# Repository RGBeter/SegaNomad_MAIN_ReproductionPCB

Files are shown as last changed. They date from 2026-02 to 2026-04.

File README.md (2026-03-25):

# Sega Nomad MAIN Reproduction PCB
Reproduction of the Sega Nomad's main board, created from scans provided by Villahed94, Sega's documentation, and community knowledge of the FC1004 style Genesis.
Additional features include TMSS bypass jumpers, SMS support and 32X support.

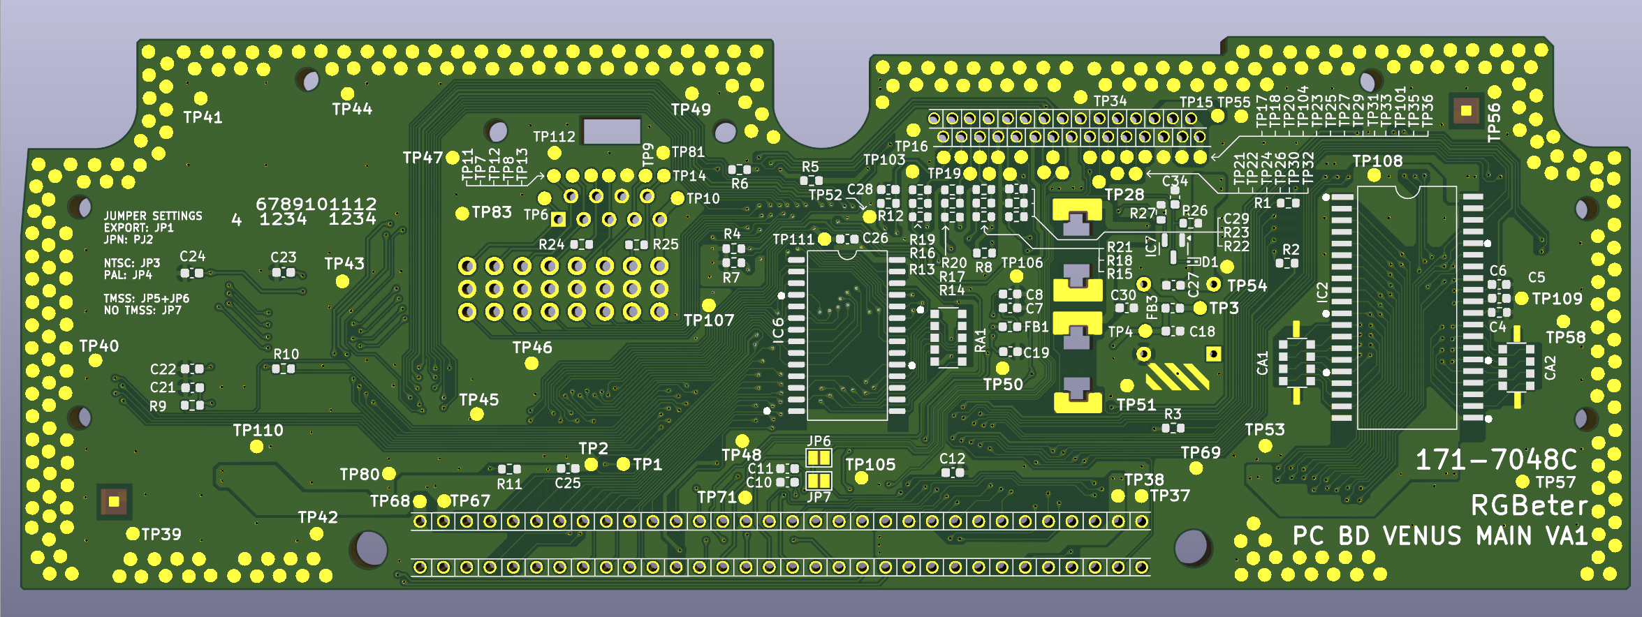
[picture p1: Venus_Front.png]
Front

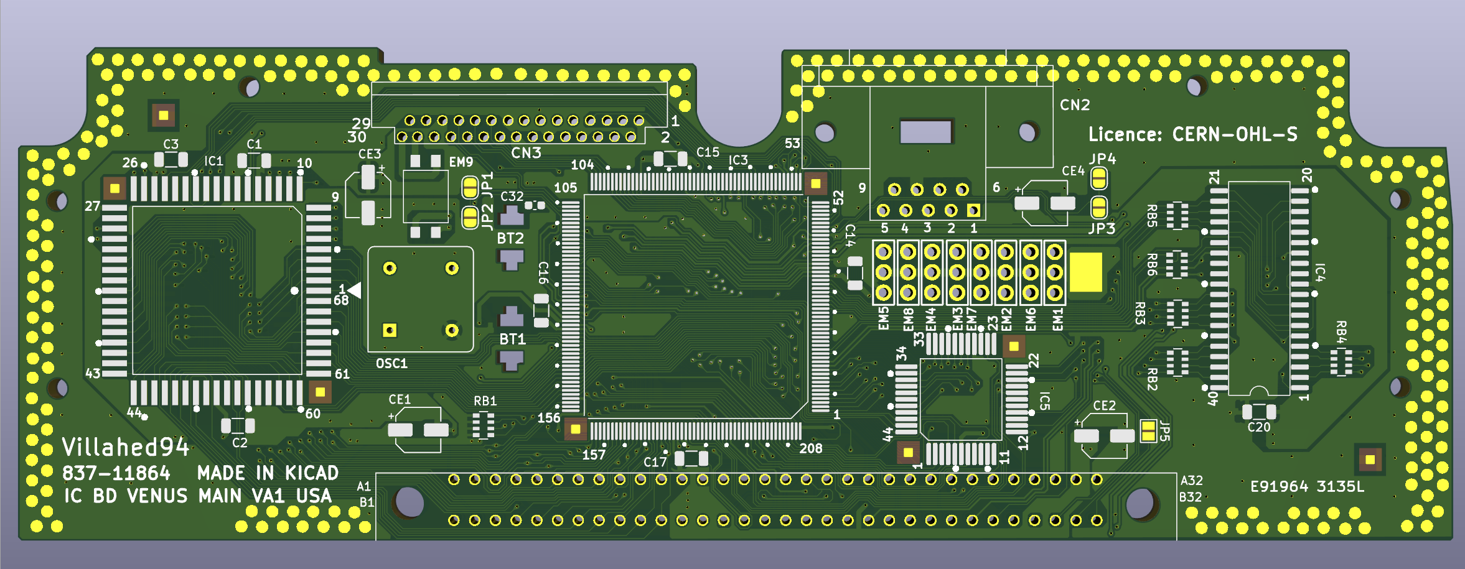
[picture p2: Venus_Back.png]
Back


# Build Notes
These PCBs are tested to work with with a stock VENUS SUB pcb, building these requires skills in microsoldering, QFP soldering, hot air rework, and Mega Drive troubleshooting.
It is highly recomendded you start with a set of known working parts from a donor MegaDrive. VA1, VA1.8 and VA3 Model 2 Sega Genesis/MegaDrive can provide all of the necessary custom chips needed for this build.
Support is not officially provided by neither RGBeter nor Villahed94 with building or debugging these PCBs.

# Production Notes
While Sega utlized a 2 layer PCB for the Nomad, it is best to order these as a 4 layer PCB in order to improve noise across the board
If you wish NOT to include the SRES bypass, add the following bodge wires in order to connect the original 315-5684 based SRES circuit.

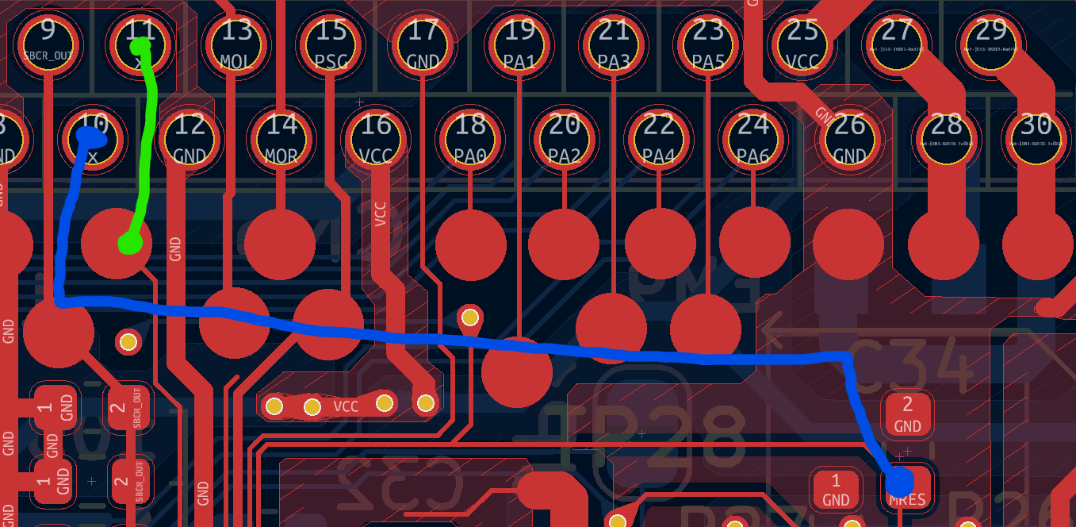
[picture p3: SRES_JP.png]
Bodge Required to use Stock SRES


# BOM
Most of, if not all parts can be directly transplanted from a donor Nomad Main board, however, some alterations have been made, and they are as follows:

R5 + R6, FM DAC limiting resistors best changed to 0 ohms when modding audio

All large MLCC capacitors can have their value increased to 10uF to improve noise

|Component|Value|Note|
|:---|:----|:---|
|IC1|PLCC 68000|CPU|
|IC2|68K RAM|WORK RAM|
|IC3|FC1004/FF1004|MAIN ASIC|
|IC4|VIDEO RAM|VRAM|
|IC5|QFP Z80|Z80 CPU|
|IC6|Z80 RAM|ZRAM|
|IC7|LM809|SRES BYPASS ONLY|
|C1|10uF|1206 X7R|
|C2|10uF|1206 X7R|
|C3|10uF|1206 X7R|
|C4|47pF|0603 C0G 315-5708 ONLY|
|C5|100pF|0603 C0G|
|C6|100pF|0603 C0G|
|C7|22pF|0603 C0G|
|C8|1000pF|0603 C0G|
|C9|N/A|DOES NOT EXIST|
|C10|100pF|0603 C0G|
|C11|100pF|0603 C0G|
|C12|33pF|0603 C0G|
|C13|N/A|DOES NOT EXIST|
|C14|10uF|1206 X7R|
|C15|10uF|1206 X7R|
|C16|10uF|1206 X7R|
|C17|10uF|1206 X7R|
|C18|20pF|0603 C0G|
|C19|47pF|0603 C0G|
|C20|10uF|1206 X7R|
|C21|33pF|0603 C0G DO NOT POPULATE|
|C22|100pF|0603 C0G|
|C23|33pF|0603 C0G|
|C24|100pF|0603 C0G|
|C25|0.1uF|0603 X7R|
|C26|0.1uF|0603 X7R|
|C27|0.1uF|0603 X7R|
|C28|N/A|DO NOT POPULATE|
|C29|100pF|0603 C0G|
|C30|0.1uF|0603 X7R|
|C31|N/A|DOES NOT EXIST|
|C32|N/A|DO NOT POPULATE|
|C33|N/A|DOES NOT EXIST|
|C30|1uF|0603 X7R SRES BYPASSS ONLY|
|CE1|47uF 6v|SMD ELEC, CAN REPLACE WITH TANTALUM|
|CE2|47uF 6v|SMD ELEC, CAN REPLACE WITH TANTALUM|
|CE3|100uF 6v|SMD ELEC, CAN REPLACE WITH TANTALUM|
|CE4|47uF 6v|SMD ELEC, CAN REPLACE WITH TANTALUM|
|D1|SOD-923 DIODE|SRES BYPASS ONLY|
|OSC1|MCLK OSCILATOR, SQUARE PACKAGE|CHECK REGION|
|R1|150R|0603|
|R2|220R|0603|
|R3|2.2K|0603|
|R4|220R|0603|
|R5|0R|0603 DAC LIMITING RESISTOR|
|R6|0R|0603 DAC LIMITING RESISTOR|
|R7|2.2K|0603|
|R8|4.7K|0603|
|R9|100R|0603|
|R10|100R|0603|
|R11|2.2K|0603|
|R12|2.2K|0603|
|R13|5.6K|0603|
|R14|5.6K|0603|
|R15|5.6K|0603|
|R16|4.7K|0603|
|R17|4.7K|0603|
|R18|4.7K|0603|
|R19|1.2K|0603|
|R20|1.2K|0603|
|R21|1.2K|0603|
|R22|4.7K|0603|
|R23|1.0K|0603|
|R24|330R|0603|
|R25|330R|0603|
|R26|2.2K|0603|
|R27|100K|0603|
|RA1|4.7K|5X1206 BANK|
|RB1|2.2K|4X0603 BANK|
|RB2|100R|4X0603 BANK|
|RB3|100R|4X0603 BANK|
|RB4|100R|4X0603 BANK|
|RB5|100R|4X0603 BANK|
|RB6|100R|4X0603 BANK|

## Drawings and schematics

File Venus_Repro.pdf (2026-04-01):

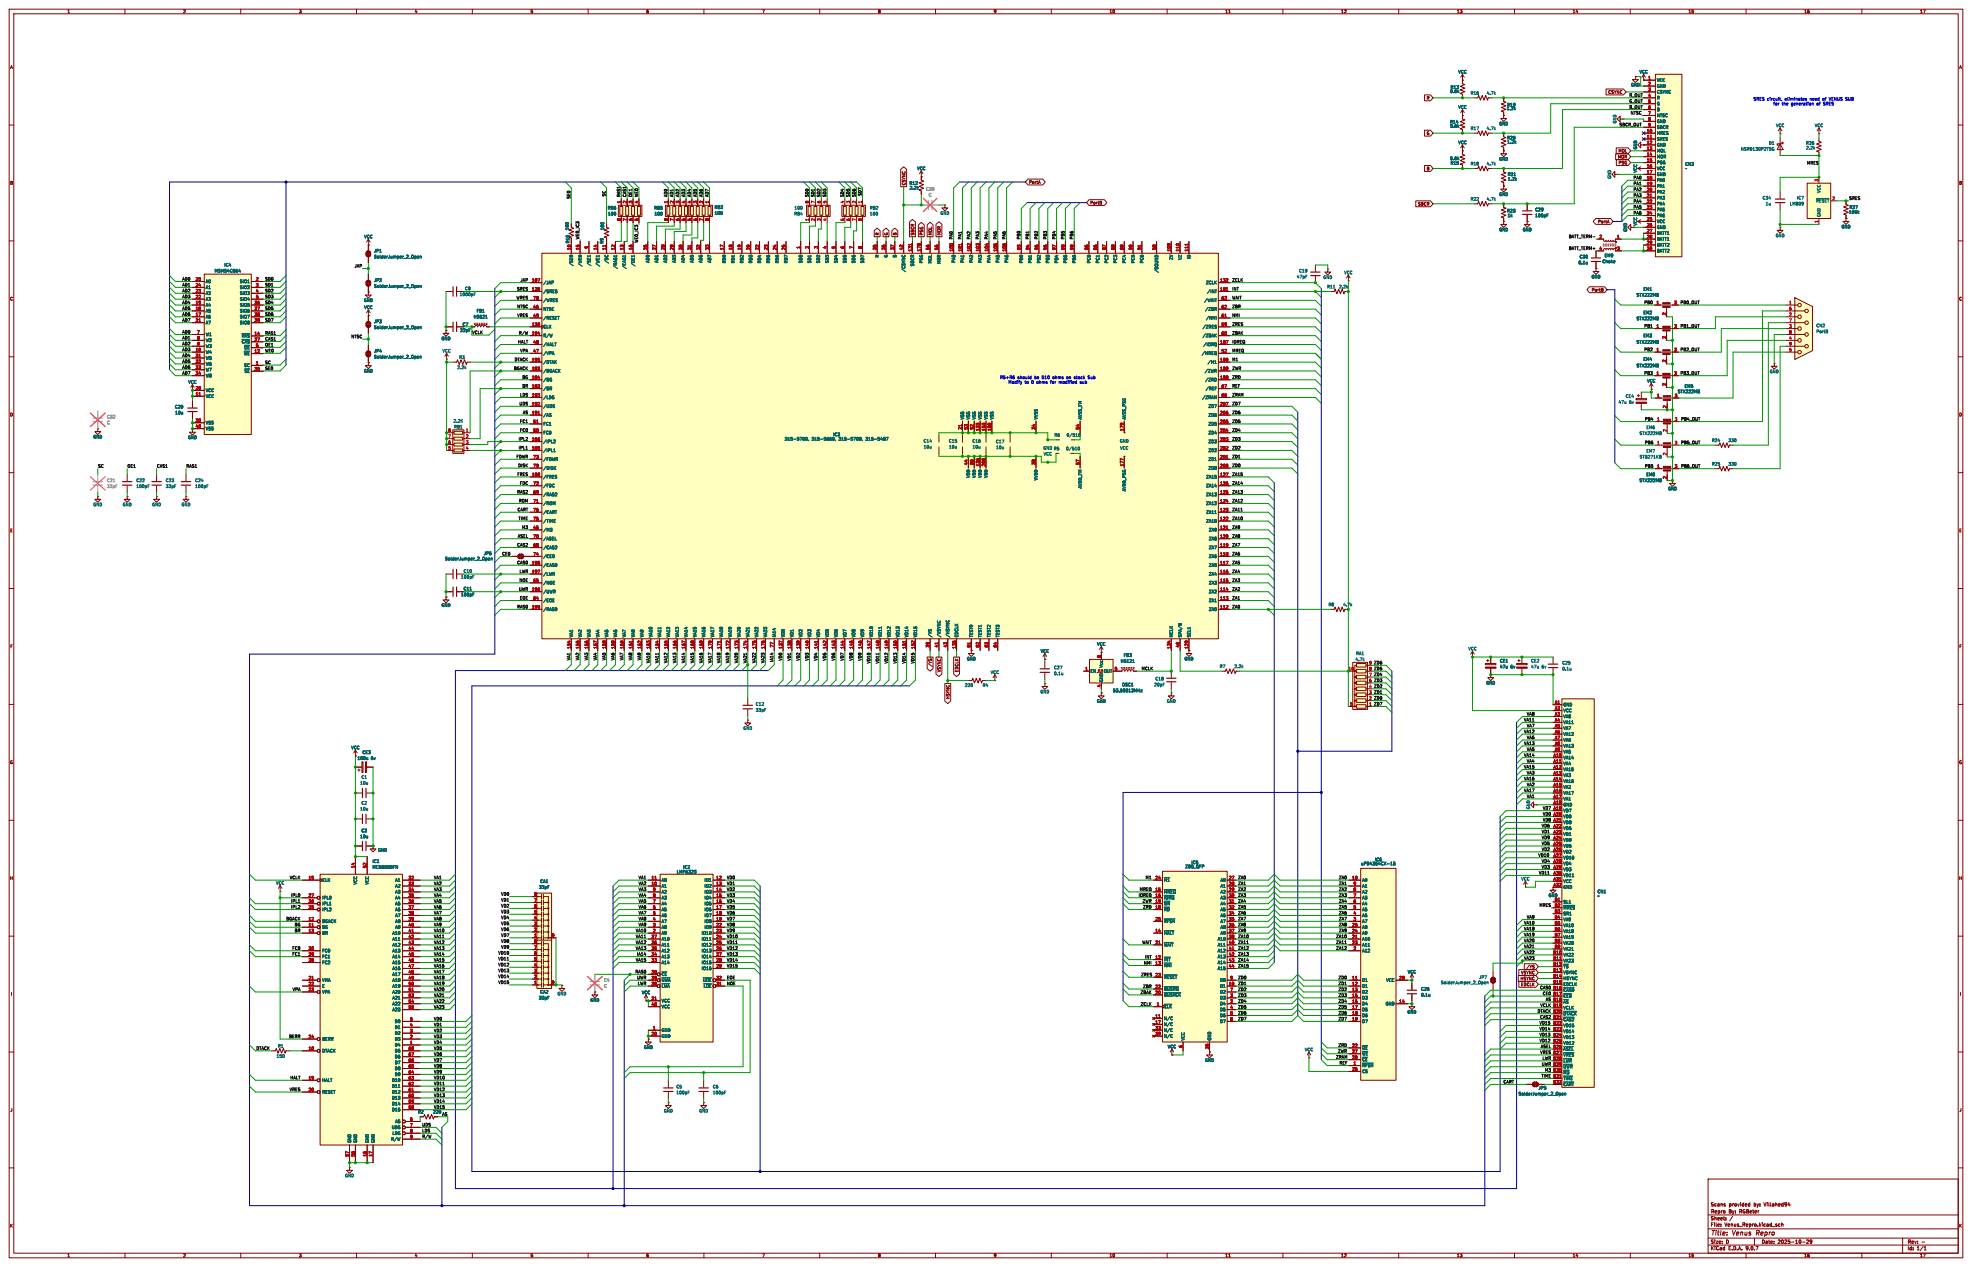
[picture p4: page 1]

8 VD9 146 VD10 147 R 35 VD11 148 G 36 VD12 149 B 37 VD13 150 /CSYNC 42 VD14 151 SBCR 131 VD15 152 PSG 178 MOL 56 /YS 39 MOR 55 /VSYNC 41 /HSYNC 43 PA0 100 EDCLK 135 PA1 101 VSS 21 VSS 53 VDD 44 PA2 102 TEST0 81 VSS 92 VDD 80 PA3 103 VSS 133 VDD 136 TEST1 82 VSS 153 VDD 208 PA4 104 TEST2 83 VSS 180 PA5 105 TEST3 84 PA6 106 PB0 93 PB1 94 VVSS 34 VVDD 38 PB2 95 PB3 96 PB4 97 PB5 98 PB6 99 AVSS_FM 54 AVDD_FM 57 PC0 85 PC1 86 PC2 87 PC3 88 PC4 89 AVSS_PSG 179 AVDD_PSG 177 PC5 90 PC6 91 /SOUND 58 ZV 109 MCLK 134 VZ 110 SPA/B 40 IO 111 SEL1 129 ZCLK

IC5 Z80_QFP
~{M1} 24 ~{MREQ} 15 ~{IORQ} 16 ~{WR} 19 ~{RD} 18 ~{RFSH} 25 ~{HALT} 14 ~{WAIT} 21 ~{INT} 12 ~{NMI} 13 ~{RESET} 23 ~{BUSRQ} 22 ~{BUSACK} 20 ~{CLK} 1 N/C

A31 GND
A32 SL1 B1 ~{MRES} B2 SR1 B3 VA9 B4 VA10 B5 VA18 B6 VA19 B7 VA20 B8 VA21 B9 VA22 B10 VA23 B11 ~{YS} B12 VSYNC
B19 ~{DTACK} B20 ~{CAS2} B21 VD15 B22 VD14 B23 VD13 B24 VD12 B25 ~{ASEL} B26 ~{VRES} B27 ~{LWR} B28 ~{UWR} B29 ~{M3} B30 ~{TIME} B31 ~{CART} B32 GND
CE0AS MRES

Id: 1/1 Title: Venus Repro

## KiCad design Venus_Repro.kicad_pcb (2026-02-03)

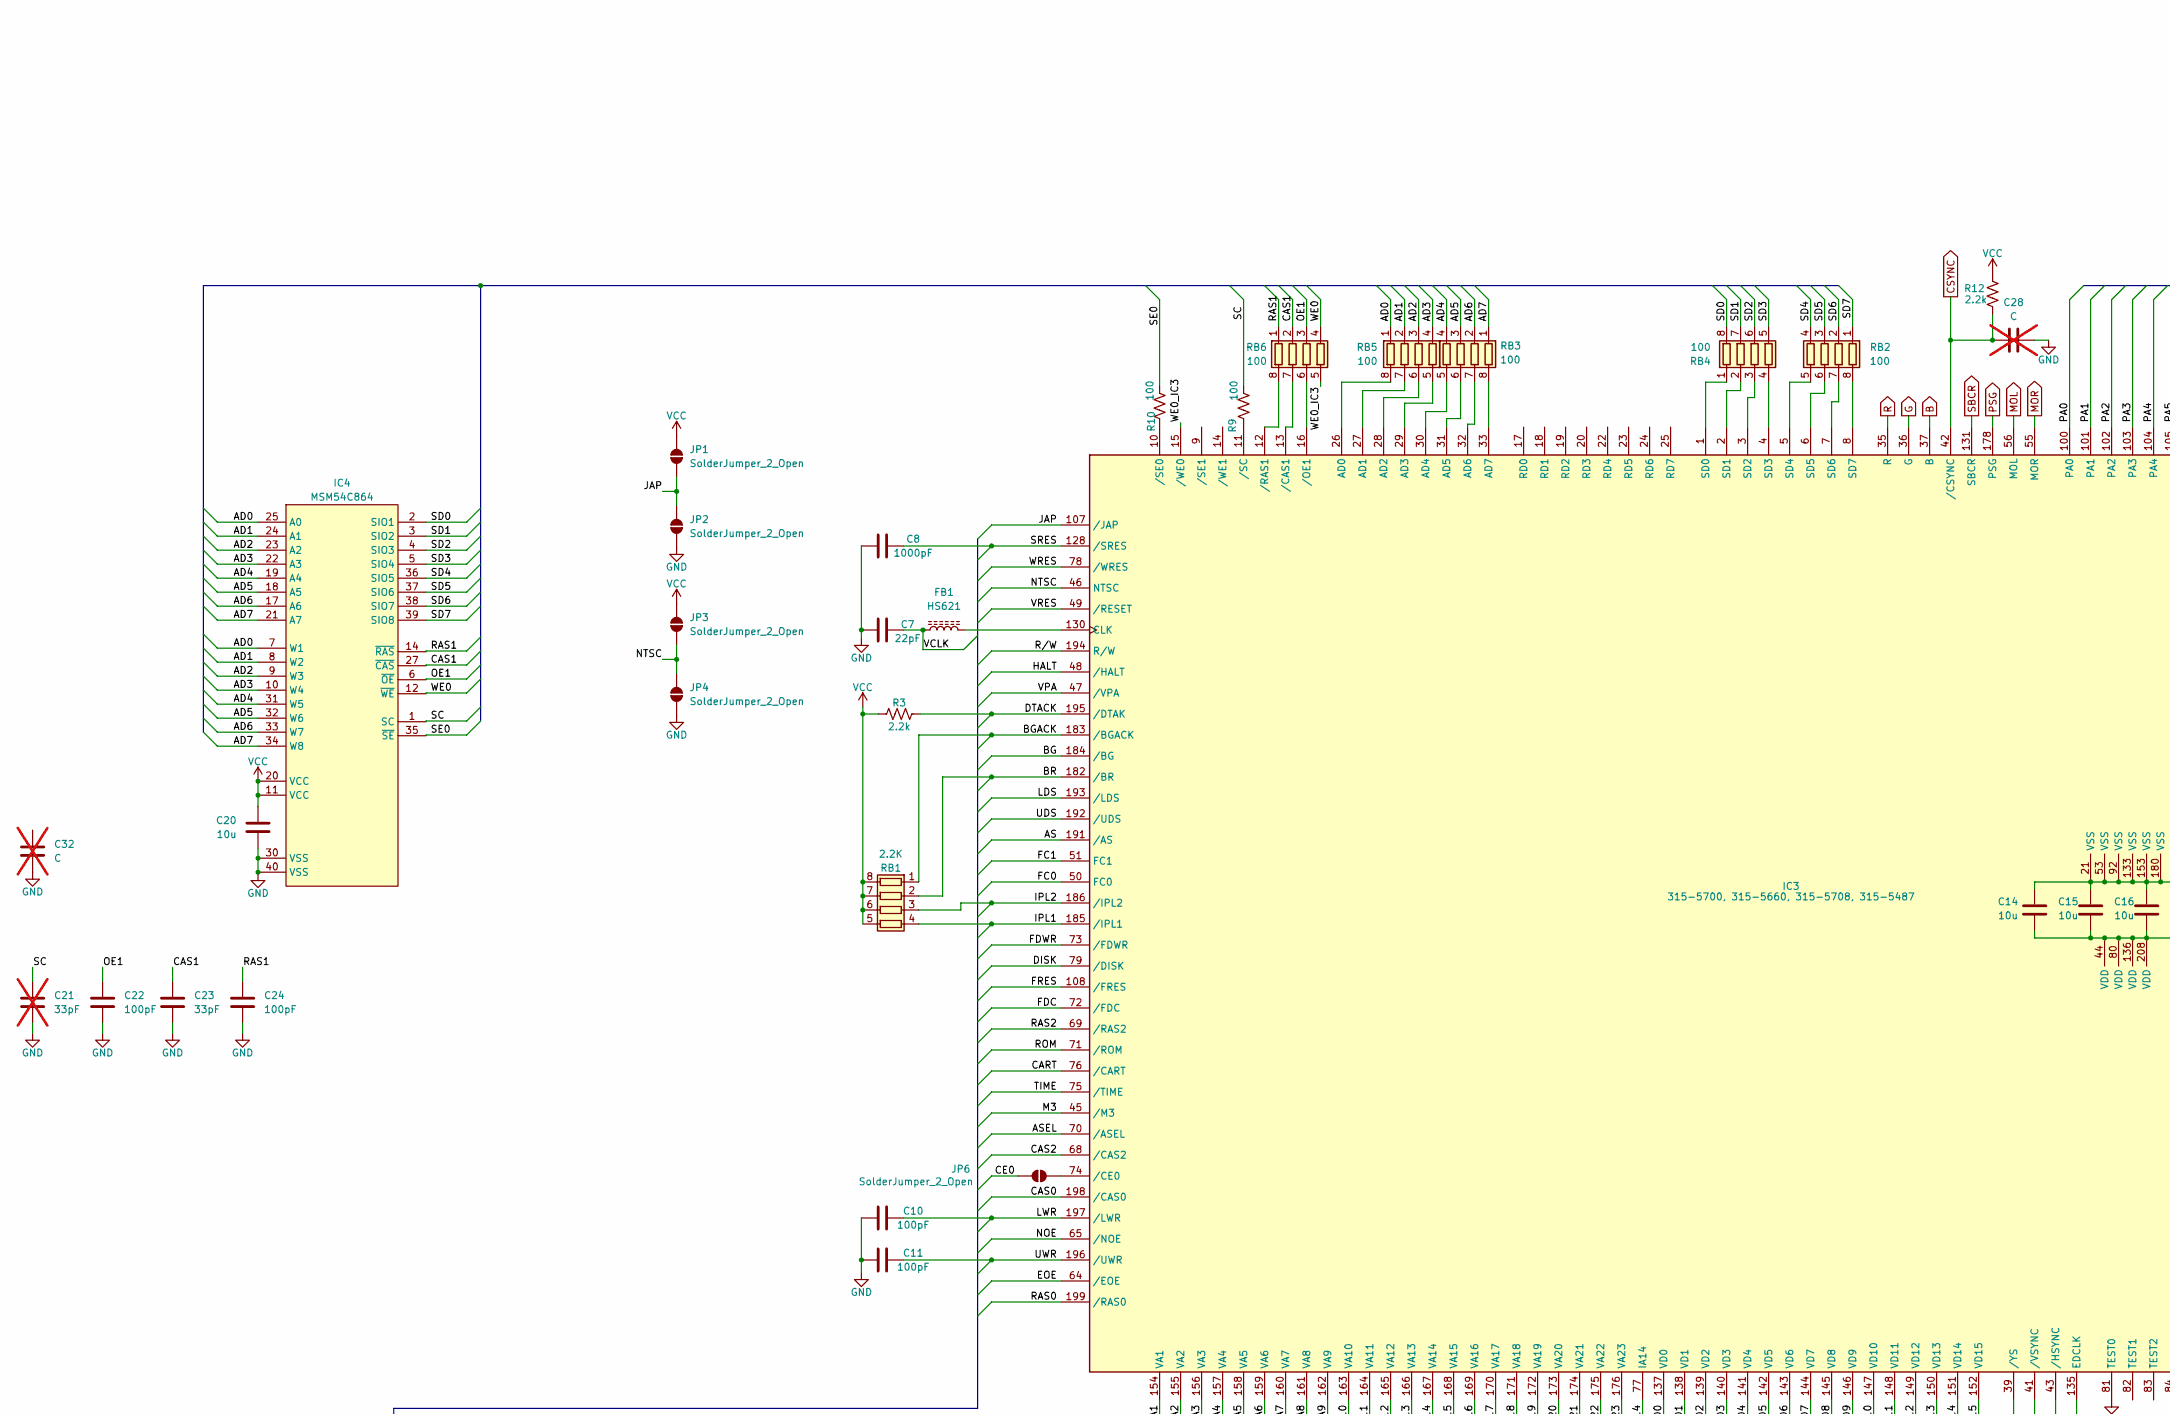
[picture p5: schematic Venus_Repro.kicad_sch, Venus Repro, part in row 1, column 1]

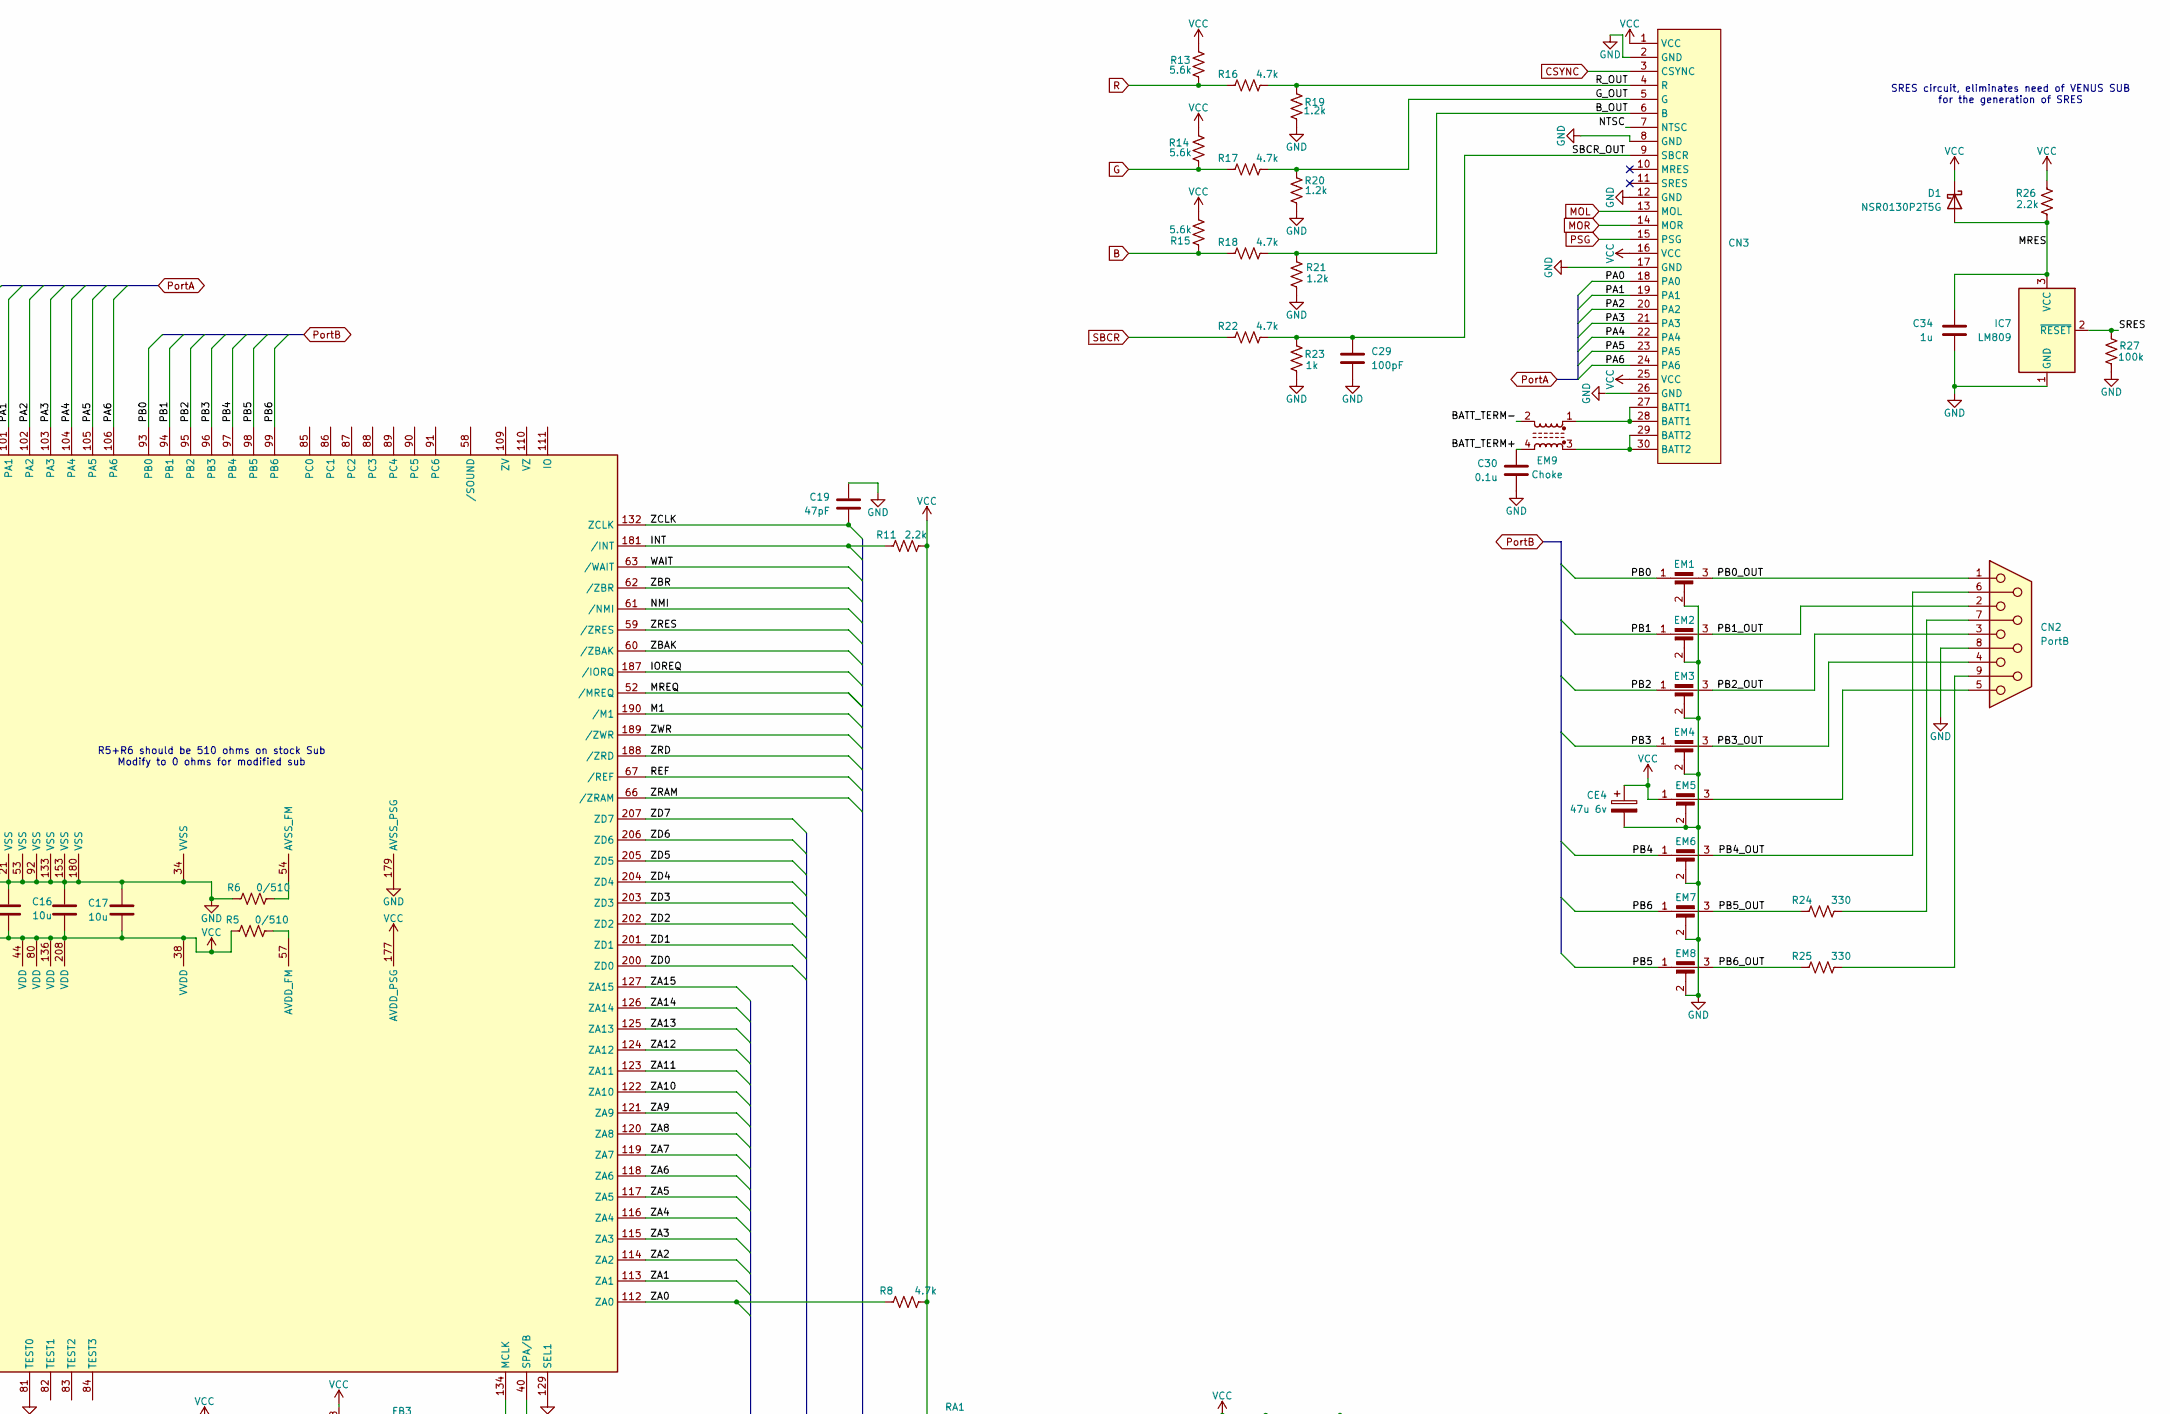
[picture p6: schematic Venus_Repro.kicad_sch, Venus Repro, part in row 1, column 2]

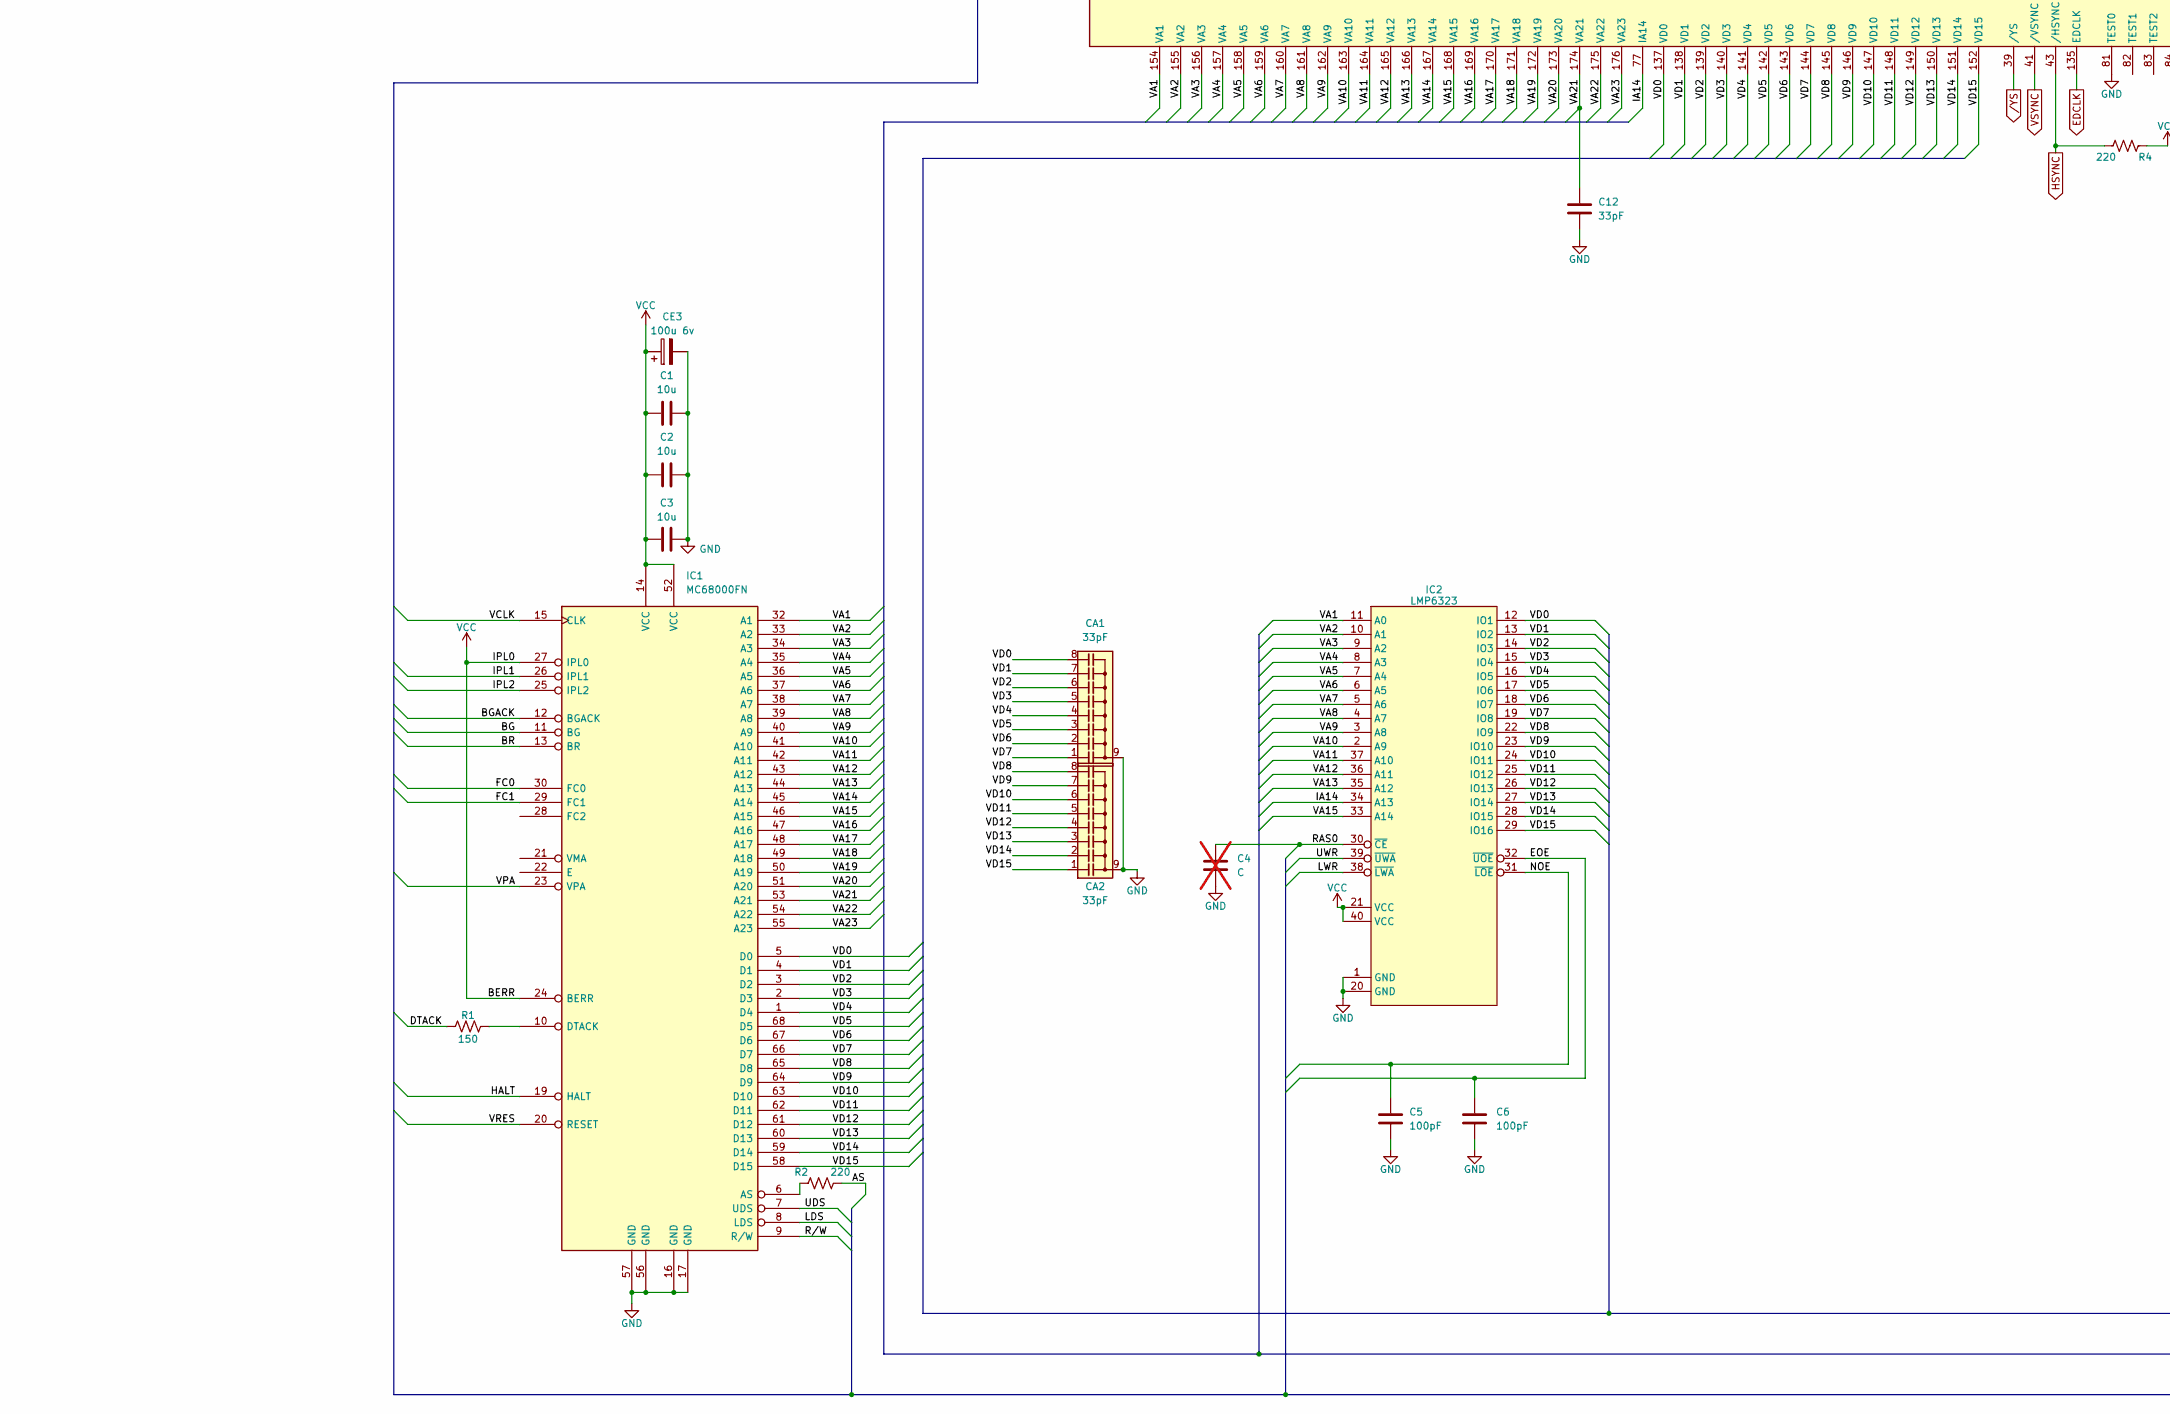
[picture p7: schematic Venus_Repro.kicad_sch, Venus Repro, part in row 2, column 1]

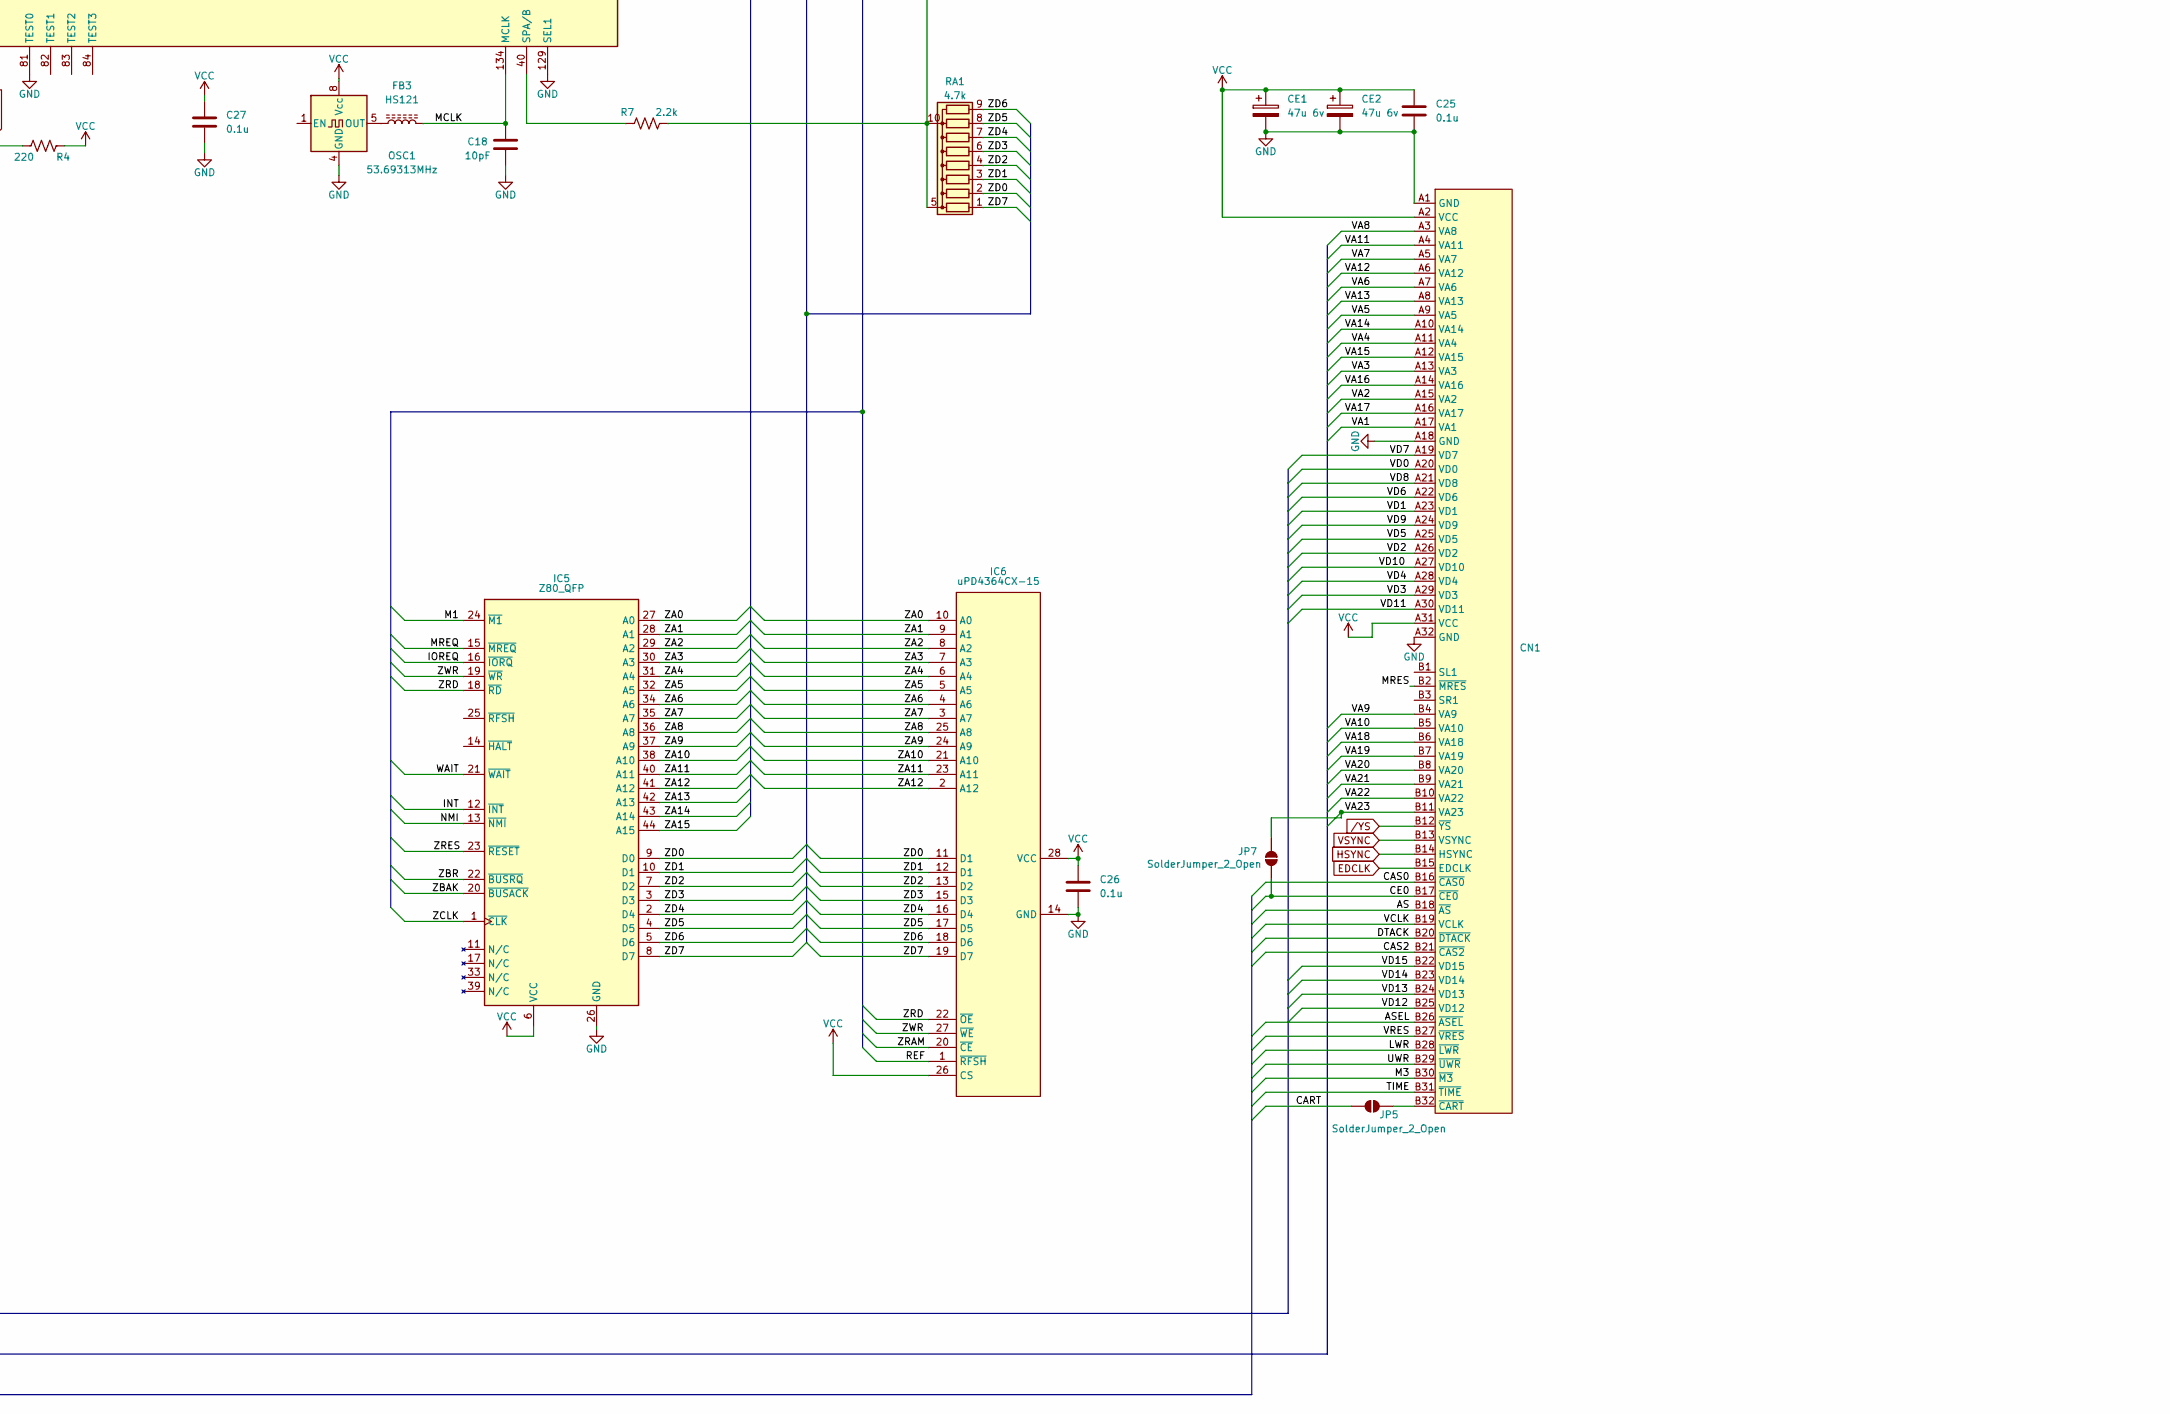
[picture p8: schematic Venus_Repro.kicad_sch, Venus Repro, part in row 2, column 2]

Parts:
C1, C2, C3, C14, C15, C16, C17, C20: 10u; C_1206_3216Metric
C4, C28, C32: C; C_0603_1608Metric; not fitted
C5, C6, C10, C11, C22, C24, C29: 100pF; C_0603_1608Metric
C7: 22pF; C_0603_1608Metric
C8: 1000pF; C_0603_1608Metric
C12, C23: 33pF; C_0603_1608Metric
C18: 10pF; C_0603_1608Metric
C19: 47pF; C_0603_1608Metric
C21: 33pF; C_0603_1608Metric; not fitted
C25, C26, C27, C30: 0.1u; C_0603_1608Metric
C34: 1u; C_0603_1608Metric
CA1, CA2: 33pF; R_Array_Convex_4x1206
CE1, CE2, CE4: 47u 6v; CP_Elec_5x4.5
CE3: 100u 6v; CP_Elec_5x4.5
CN1: Venus_Cartidge_Slot
CN2: PortB; DSUB-9_Pins_Horizontal_P2.77x2.54mm_EdgePinOffset9.40mm
CN3: Venus_FFC
D1: NSR0130P2T5G; D_SOD-923
EM1, EM2, EM3, EM4, EM5, EM6, EM7, EM8: Venus_EMI
EM9: Choke; L_CommonModeChoke
FB1: HS621; L_0603_1608Metric
FB3: HS121; L_0603_1608Metric
IC1: MC68000FN; PLCC-68
IC2: LMP6323; Venus_WRAM
IC3: 315-5700, 315-5660, 315-5708, 315-5487; LQFP-208_28x28mm_P0.5mm
IC4: MSM54C864; SOJ-40
IC5: Z80_QFP; LQFP-44_Z80_10x10mm_P0.8mm
IC6: uPD4364CX-15; SOIC-28W_7.5x18.7mm_P1.27mm
IC7: LM809; SOT-23
JP1, JP2, JP3, JP4: SolderJumper_2_Open; SolderJumper-2_P1.3mm_Open_RoundedPad1.0x1.5mm
JP5, JP6, JP7: SolderJumper_2_Open; SolderJumper-2_P1.3mm_Open_Pad1.0x1.5mm
OSC1: 53.69313MHz; Oscillator_DIP-8
R1: 150; R_0603_1608Metric
R2, R4: 220; R_0603_1608Metric
R3, R7, R11, R12, R26: 2.2k; R_0603_1608Metric
R5, R6: 0/510; R_0603_1608Metric
R8, R16, R17, R18, R22: 4.7k; R_0603_1608Metric
R9, R10: 100; R_0603_1608Metric
R13, R14, R15: 5.6k; R_0603_1608Metric
R19, R20, R21: 1.2k; R_0603_1608Metric
R23: 1k; R_0603_1608Metric
R24, R25: 330; R_0603_1608Metric
R27: 100k; R_0603_1608Metric
RA1: 4.7k; R_Array_Convex_5x1206
RB1: 2.2K; R_Array_Convex_4x0603
RB2, RB3, RB4, RB5, RB6: 100; R_Array_Convex_4x0603

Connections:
/AD0: IC4.7 (W1), IC4.25 (A0), RB5.1 (R1.1)
/AD1: IC4.8 (W2), IC4.24 (A1), RB5.2 (R2.1)
/AD2: IC4.9 (W3), IC4.23 (A2), RB5.3 (R3.1)
/AD3: IC4.10 (W4), IC4.22 (A3), RB5.4 (R4.1)
/AD4: IC4.19 (A4), IC4.31 (W5), RB3.4 (R4.1)
/AD5: IC4.18 (A5), IC4.32 (W6), RB3.3 (R3.1)
/AD6: IC4.17 (A6), IC4.33 (W7), RB3.2 (R2.1)
/AD7: IC4.21 (A7), IC4.34 (W8), RB3.1 (R1.1)
/AS: CN1.B18 (~AS), IC3.191 (/AS), R2.2
/ASEL: CN1.B26 (~ASEL), IC3.70 (/ASEL)
/BATT_TERM+: C30.2, EM9.4
/BATT_TERM-: EM9.2
/BG: IC1.11 (BG), IC3.184 (/BG)
/BGACK: IC1.12 (BGACK), IC3.183 (/BGACK), RB1.1 (R1.1)
/BR: IC1.13 (BR), IC3.182 (/BR), RB1.2 (R2.1)
/B_OUT: CN3.6 (B), R18.2, R21.2
/CART: IC3.76 (/CART), JP5.2 (B)
/CAS0: CN1.B16 (~CAS0), IC3.198 (/CAS0)
/CAS1: C23.1, IC4.27 (~CAS), RB6.2 (R2.1)
/CAS2: CN1.B21 (~CAS2), IC3.68 (/CAS2)
/CE0: CN1.B17 (~CE0), JP6.1 (A), JP7.2 (B)
/DISK: IC3.79 (/DISK)
/DTACK: CN1.B20 (~DTACK), IC3.195 (/DTAK), R1.1, R3.2
/EOE: C6.1, IC2.32 (~UOE), IC3.64 (/EOE)
/FC0: IC1.30 (FC0), IC3.50 (FC0)
/FC1: IC1.29 (FC1), IC3.51 (FC1)
/FDC: IC3.72 (/FDC)
/FDWR: IC3.73 (/FDWR)
/FRES: IC3.108 (/FRES)
/G_OUT: CN3.5 (G), R17.2, R20.2
/HALT: IC1.19 (HALT), IC3.48 (/HALT)
/IA14: IC2.34 (A13), IC3.77 (IA14)
/INT: IC3.181 (/INT), IC5.12 (~INT), R11.1
/IOREQ: IC3.187 (/IORQ), IC5.16 (~IORQ)
/IPL1: IC1.26 (IPL1), IC3.185 (/IPL1), RB1.4 (R4.1)
/IPL2: IC1.25 (IPL2), IC3.186 (/IPL2), RB1.3 (R3.1)
/JAP: IC3.107 (/JAP), JP1.1 (A), JP2.2 (B)
/LDS: IC1.8 (LDS), IC3.193 (/LDS)
/LWR: C10.2, CN1.B28 (~LWR), IC2.38 (~LWA), IC3.197 (/LWR)
/M1: IC3.190 (/M1), IC5.24 (~M1)
/M3: CN1.B30 (~M3), IC3.45 (/M3)
/MCLK: C18.1, FB3.2, IC3.134 (MCLK)
/MREQ: IC3.52 (/MREQ), IC5.15 (~MREQ)
/MRES: C34.1, CN1.B2 (~MRES), D1.2 (A), IC7.3 (VCC), R26.1
/NMI: IC3.61 (/NMI), IC5.13 (~NMI)
/NOE: C5.2, IC2.31 (~LOE), IC3.65 (/NOE)
/NTSC: CN3.7 (NTSC), IC3.46 (NTSC), JP3.1 (A), JP4.2 (B)
/OE1: C22.1, IC4.6 (~OE), RB6.3 (R3.1)
/PA0: CN3.18 (PA0), IC3.100 (PA0)
/PA1: CN3.19 (PA1), IC3.101 (PA1)
/PA2: CN3.20 (PA2), IC3.102 (PA2)
/PA3: CN3.21 (PA3), IC3.103 (PA3)
/PA4: CN3.22 (PA4), IC3.104 (PA4)
/PA5: CN3.23 (PA5), IC3.105 (PA5)
/PA6: CN3.24 (PA6), IC3.106 (PA6)
/PB0: EM1.1, IC3.93 (PB0)
/PB0_OUT: CN2.1, EM1.3
/PB1: EM2.1, IC3.94 (PB1)
/PB1_OUT: CN2.2, EM2.3
/PB2: EM3.1, IC3.95 (PB2)
/PB2_OUT: CN2.3, EM3.3
/PB3: EM4.1, IC3.96 (PB3)
/PB3_OUT: CN2.4, EM4.3
/PB4: EM6.1, IC3.97 (PB4)
/PB4_OUT: CN2.6, EM6.3
/PB5: EM8.1, IC3.98 (PB5)
/PB5_OUT: EM7.3, R24.1
/PB6: EM7.1, IC3.99 (PB6)
/PB6_OUT: EM8.3, R25.1
/RAS0: C4.1, IC2.30 (~CE), IC3.199 (/RAS0)
/RAS1: C24.1, IC4.14 (~RAS), RB6.1 (R1.1)
/RAS2: IC3.69 (/RAS2)
/REF: IC3.67 (/REF), IC6.1 (~RFSH)
/ROM: IC3.71 (/ROM)
/R_OUT: CN3.4 (R), R16.2, R19.1
/R/W: IC1.9 (R/W), IC3.194 (R/W)
/SBCR_OUT: C29.2, CN3.9 (SBCR), R22.2, R23.2
/SC: C21.1, IC4.1 (SC), R9.2
/SD0: IC4.2 (SIO1), RB4.8 (R1.2)
/SD1: IC4.3 (SIO2), RB4.7 (R2.2)
/SD2: IC4.4 (SIO3), RB4.6 (R3.2)
/SD3: IC4.5 (SIO4), RB4.5 (R4.2)
/SD4: IC4.36 (SIO5), RB2.4 (R4.1)
/SD5: IC4.37 (SIO6), RB2.3 (R3.1)
/SD6: IC4.38 (SIO7), RB2.2 (R2.1)
/SD7: IC4.39 (SIO8), RB2.1 (R1.1)
/SE0: IC4.35 (~SE), R10.2
/SRES: C8.2, IC3.128 (/SRES), IC7.2 (~RESET), R27.2
/TIME: CN1.B31 (~TIME), IC3.75 (/TIME)
/UDS: IC1.7 (UDS), IC3.192 (/UDS)
/UWR: C11.2, CN1.B29 (~UWR), IC2.39 (~UWA), IC3.196 (/UWR)
/VA1: CN1.A17 (VA1), IC1.32 (A1), IC2.11 (A0), IC3.154 (VA1)
/VA2: CN1.A15 (VA2), IC1.33 (A2), IC2.10 (A1), IC3.155 (VA2)
/VA3: CN1.A13 (VA3), IC1.34 (A3), IC2.9 (A2), IC3.156 (VA3)
/VA4: CN1.A11 (VA4), IC1.35 (A4), IC2.8 (A3), IC3.157 (VA4)
/VA5: CN1.A9 (VA5), IC1.36 (A5), IC2.7 (A4), IC3.158 (VA5)
/VA6: CN1.A7 (VA6), IC1.37 (A6), IC2.6 (A5), IC3.159 (VA6)
/VA7: CN1.A5 (VA7), IC1.38 (A7), IC2.5 (A6), IC3.160 (VA7)
/VA8: CN1.A3 (VA8), IC1.39 (A8), IC2.4 (A7), IC3.161 (VA8)
/VA9: CN1.B4 (VA9), IC1.40 (A9), IC2.3 (A8), IC3.162 (VA9)
/VA10: CN1.B5 (VA10), IC1.41 (A10), IC2.2 (A9), IC3.163 (VA10)
/VA11: CN1.A4 (VA11), IC1.42 (A11), IC2.37 (A10), IC3.164 (VA11)
/VA12: CN1.A6 (VA12), IC1.43 (A12), IC2.36 (A11), IC3.165 (VA12)
/VA13: CN1.A8 (VA13), IC1.44 (A13), IC2.35 (A12), IC3.166 (VA13)
/VA14: CN1.A10 (VA14), IC1.45 (A14), IC3.167 (VA14)
/VA15: CN1.A12 (VA15), IC1.46 (A15), IC2.33 (A14), IC3.168 (VA15)
/VA16: CN1.A14 (VA16), IC1.47 (A16), IC3.169 (VA16)
/VA17: CN1.A16 (VA17), IC1.48 (A17), IC3.170 (VA17)
/VA18: CN1.B6 (VA18), IC1.49 (A18), IC3.171 (VA18)
/VA19: CN1.B7 (VA19), IC1.50 (A19), IC3.172 (VA19)
/VA20: CN1.B8 (VA20), IC1.51 (A20), IC3.173 (VA20)
/VA21: C12.2, CN1.B9 (VA21), IC1.53 (A21), IC3.174 (VA21)
/VA22: CN1.B10 (VA22), IC1.54 (A22), IC3.175 (VA22)
/VA23: CN1.B11 (VA23), IC1.55 (A23), IC3.176 (VA23), JP7.1 (A)
/VCLK: C7.2, CN1.B19 (VCLK), FB1.1, IC1.15 (CLK)
/VD0: CA1.8 (C7), CN1.A20 (VD0), IC1.5 (D0), IC2.12 (IO1), IC3.137 (VD0)
/VD1: CA1.7 (C6), CN1.A23 (VD1), IC1.4 (D1), IC2.13 (IO2), IC3.138 (VD1)
/VD2: CA1.6 (C5), CN1.A26 (VD2), IC1.3 (D2), IC2.14 (IO3), IC3.139 (VD2)
/VD3: CA1.5 (C4), CN1.A29 (VD3), IC1.2 (D3), IC2.15 (IO4), IC3.140 (VD3)
/VD4: CA1.4 (C3), CN1.A28 (VD4), IC1.1 (D4), IC2.16 (IO5), IC3.141 (VD4)
/VD5: CA1.3 (C2), CN1.A25 (VD5), IC1.68 (D5), IC2.17 (IO6), IC3.142 (VD5)
/VD6: CA1.2 (C1), CN1.A22 (VD6), IC1.67 (D6), IC2.18 (IO7), IC3.143 (VD6)
/VD7: CA1.1 (C8), CN1.A19 (VD7), IC1.66 (D7), IC2.19 (IO8), IC3.144 (VD7)
/VD8: CA2.8 (C7), CN1.A21 (VD8), IC1.65 (D8), IC2.22 (IO9), IC3.145 (VD8)
/VD9: CA2.7 (C6), CN1.A24 (VD9), IC1.64 (D9), IC2.23 (IO10), IC3.146 (VD9)
/VD10: CA2.6 (C5), CN1.A27 (VD10), IC1.63 (D10), IC2.24 (IO11), IC3.147 (VD10)
/VD11: CA2.5 (C4), CN1.A30 (VD11), IC1.62 (D11), IC2.25 (IO12), IC3.148 (VD11)
/VD12: CA2.4 (C3), CN1.B25 (VD12), IC1.61 (D12), IC2.26 (IO13), IC3.149 (VD12)
/VD13: CA2.3 (C2), CN1.B24 (VD13), IC1.60 (D13), IC2.27 (IO14), IC3.150 (VD13)
/VD14: CA2.2 (C1), CN1.B23 (VD14), IC1.59 (D14), IC2.28 (IO15), IC3.151 (VD14)
/VD15: CA2.1 (C8), CN1.B22 (VD15), IC1.58 (D15), IC2.29 (IO16), IC3.152 (VD15)
/VPA: IC1.23 (VPA), IC3.47 (/VPA)
/VRES: CN1.B27 (~VRES), IC1.20 (RESET), IC3.49 (/RESET)
/WAIT: IC3.63 (/WAIT), IC5.21 (~WAIT)
/WE0: IC4.12 (~WE), RB6.4 (R4.1)
/WE0_IC3: IC3.15 (/WE0), RB6.5 (R4.2)
/WRES: IC3.78 (/WRES)
/ZA0: IC3.112 (ZA0), IC5.27 (A0), IC6.10 (A0), R8.1
/ZA1: IC3.113 (ZA1), IC5.28 (A1), IC6.9 (A1)
/ZA2: IC3.114 (ZA2), IC5.29 (A2), IC6.8 (A2)
/ZA3: IC3.115 (ZA3), IC5.30 (A3), IC6.7 (A3)
/ZA4: IC3.116 (ZA4), IC5.31 (A4), IC6.6 (A4)
/ZA5: IC3.117 (ZA5), IC5.32 (A5), IC6.5 (A5)
/ZA6: IC3.118 (ZA6), IC5.34 (A6), IC6.4 (A6)
/ZA7: IC3.119 (ZA7), IC5.35 (A7), IC6.3 (A7)
/ZA8: IC3.120 (ZA8), IC5.36 (A8), IC6.25 (A8)
/ZA9: IC3.121 (ZA9), IC5.37 (A9), IC6.24 (A9)
/ZA10: IC3.122 (ZA10), IC5.38 (A10), IC6.21 (A10)
/ZA11: IC3.123 (ZA11), IC5.40 (A11), IC6.23 (A11)
/ZA12: IC3.124 (ZA12), IC5.41 (A12), IC6.2 (A12)
/ZA13: IC3.125 (ZA13), IC5.42 (A13)
/ZA14: IC3.126 (ZA14), IC5.43 (A14)
/ZA15: IC3.127 (ZA15), IC5.44 (A15)
/ZBAK: IC3.60 (/ZBAK), IC5.20 (~BUSACK)
/ZBR: IC3.62 (/ZBR), IC5.22 (~BUSRQ)
/ZCLK: C19.1, IC3.132 (ZCLK), IC5.1 (~CLK)
/ZD0: IC3.200 (ZD0), IC5.9 (D0), IC6.11 (D1), RA1.2 (R2)
/ZD1: IC3.201 (ZD1), IC5.10 (D1), IC6.12 (D1), RA1.3 (R3)
/ZD2: IC3.202 (ZD2), IC5.7 (D2), IC6.13 (D2), RA1.4 (R4)
/ZD3: IC3.203 (ZD3), IC5.3 (D3), IC6.15 (D3), RA1.6 (R5)
/ZD4: IC3.204 (ZD4), IC5.2 (D4), IC6.16 (D4), RA1.7 (R6)
/ZD5: IC3.205 (ZD5), IC5.4 (D5), IC6.17 (D5), RA1.8 (R7)
/ZD6: IC3.206 (ZD6), IC5.5 (D6), IC6.18 (D6), RA1.9 (R8)
/ZD7: IC3.207 (ZD7), IC5.8 (D7), IC6.19 (D7), RA1.1 (R1)
/ZRAM: IC3.66 (/ZRAM), IC6.20 (~CE)
/ZRD: IC3.188 (/ZRD), IC5.18 (~RD), IC6.22 (~OE)
/ZRES: IC3.59 (/ZRES), IC5.23 (~RESET)
/ZWR: IC3.189 (/ZWR), IC5.19 (~WR), IC6.27 (~WE)
B: IC3.37 (B), R15.1, R18.1
CSYNC: C28.1, CN3.3 (CSYNC), IC3.42 (/CSYNC), R12.1
EDCLK: CN1.B15 (EDCLK), IC3.135 (EDCLK)
G: IC3.36 (G), R14.1, R17.1
GND: C1.2, C2.2, C3.2, C4.2, C5.1, C6.2, C7.1, C8.1, C10.1, C11.1, C12.1, C14.2, C15.2, C16.2, C17.2, C18.2, C19.2, C20.2, C21.2, C22.2, C23.2, C24.2, C25.2, C26.2, C27.2, C28.2, C29.1, C30.1, C32.2, C34.2, CA1.9 (common), CA2.9 (common), CE1.2, CE2.2, CE3.2, CE4.2, CN1.A1 (GND), CN1.A18 (GND), CN1.A32 (GND), CN2.8, CN3.2 (GND), CN3.8 (GND), CN3.12 (GND), CN3.17 (GND), CN3.26 (GND), EM1.2, EM2.2, EM3.2, EM4.2, EM5.2, EM6.2, EM7.2, EM8.2, IC1.16 (GND), IC1.17 (GND), IC1.56 (GND), IC1.57 (GND), IC2.1 (GND), IC2.20 (GND), IC3.21 (VSS), IC3.34 (VVSS), IC3.53 (VSS), IC3.81 (TEST0), IC3.92 (VSS), IC3.129 (SEL1), IC3.133 (VSS), IC3.153 (VSS), IC3.179 (AVSS_PSG), IC3.180 (VSS), IC4.30 (VSS), IC4.40 (VSS), IC5.26 (GND), IC6.14 (GND), IC7.1 (GND), JP2.1 (A), JP4.1 (A), OSC1.4 (GND), R6.1, R19.2, R20.1, R21.1, R23.1, R27.1
HSYNC: CN1.B14 (HSYNC), IC3.43 (/HSYNC), R4.2
MOL: CN3.13 (MOL), IC3.56 (MOL)
MOR: CN3.14 (MOR), IC3.55 (MOR)
unnamed: CN1.B32 (~CART), JP5.1 (A)
unnamed: CN2.5, EM5.3
unnamed: CN2.7, R24.2
unnamed: CN2.9, R25.2
unnamed: CN3.27 (BATT1), CN3.28 (BATT1), EM9.1
unnamed: CN3.29 (BATT2), CN3.30 (BATT2), EM9.3
unnamed: IC1.6 (AS), R2.1
unnamed: IC1.10 (DTACK), R1.2
unnamed: IC3.26 (AD0), RB5.8 (R1.2)
unnamed: IC3.27 (AD1), RB5.7 (R2.2)
unnamed: IC3.28 (AD2), RB5.6 (R3.2)
unnamed: IC3.29 (AD3), RB5.5 (R4.2)
unnamed: IC3.30 (AD4), RB3.5 (R4.2)
unnamed: IC3.31 (AD5), RB3.6 (R3.2)
unnamed: IC3.32 (AD6), RB3.7 (R2.2)
unnamed: IC3.33 (AD7), RB3.8 (R1.2)
unnamed: IC3.57 (AVDD_FM), R5.2
unnamed: IC3.54 (AVSS_FM), R6.2
unnamed: FB1.2, IC3.130 (CLK)
unnamed: IC3.1 (SD0), RB4.1 (R1.1)
unnamed: IC3.2 (SD1), RB4.2 (R2.1)
unnamed: IC3.3 (SD2), RB4.3 (R3.1)
unnamed: IC3.4 (SD3), RB4.4 (R4.1)
unnamed: IC3.5 (SD4), RB2.5 (R4.2)
unnamed: IC3.6 (SD5), RB2.6 (R3.2)
unnamed: IC3.7 (SD6), RB2.7 (R2.2)
unnamed: IC3.8 (SD7), RB2.8 (R1.2)
unnamed: IC3.40 (SPA/B), R7.1
unnamed: IC3.13 (/CAS1), RB6.7 (R2.2)
unnamed: IC3.74 (/CE0), JP6.2 (B)
unnamed: IC3.16 (/OE1), RB6.6 (R3.2)
unnamed: IC3.12 (/RAS1), RB6.8 (R1.2)
unnamed: IC3.11 (/SC), R9.1
unnamed: IC3.10 (/SE0), R10.1
unnamed: FB3.1, OSC1.5 (OUT)
PSG: CN3.15 (PSG), IC3.178 (PSG)
R: IC3.35 (R), R13.1, R16.1
SBCR: IC3.131 (SBCR), R22.1
VCC: C1.1, C2.1, C3.1, C14.1, C15.1, C16.1, C17.1, C20.1, C25.1, C26.1, C27.1, CE1.1, CE2.1, CE3.1, CE4.1, CN1.A2 (VCC), CN1.A31 (VCC), CN3.1 (VCC), CN3.16 (VCC), CN3.25 (VCC), D1.1 (K), EM5.1, IC1.14 (VCC), IC1.24 (BERR), IC1.27 (IPL0), IC1.52 (VCC), IC2.21 (VCC), IC2.40 (VCC), IC3.38 (VVDD), IC3.44 (VDD), IC3.80 (VDD), IC3.136 (VDD), IC3.177 (AVDD_PSG), IC3.208 (VDD), IC4.11 (VCC), IC4.20 (VCC), IC5.6 (VCC), IC6.26 (CS), IC6.28 (VCC), JP1.2 (B), JP3.2 (B), OSC1.8 (Vcc), R3.1, R4.1, R5.1, R7.2, R8.2, R11.2, R12.2, R13.2, R14.2, R15.2, R26.2, RA1.5 (common), RA1.10 (common), RB1.5 (R4.2), RB1.6 (R3.2), RB1.7 (R2.2), RB1.8 (R1.2)
VSYNC: CN1.B13 (VSYNC), IC3.41 (/VSYNC)
/YS: CN1.B12 (~YS), IC3.39 (/YS)

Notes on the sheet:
SRES circuit, eliminates need of VENUS SUB for the generation of SRES
R5+R6 should be 510 ohms on stock Sub Modify to 0 ohms for modified sub

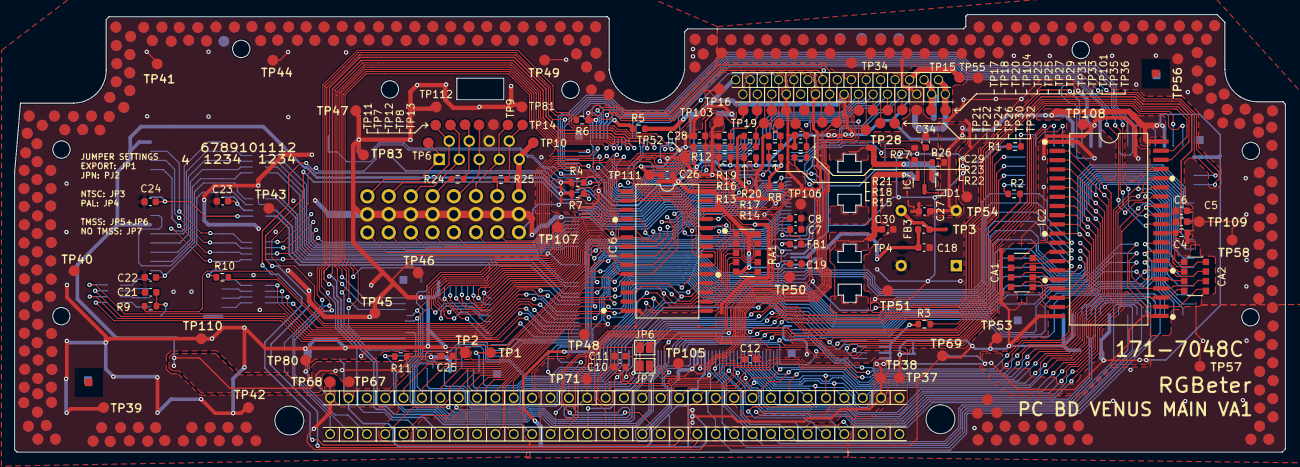
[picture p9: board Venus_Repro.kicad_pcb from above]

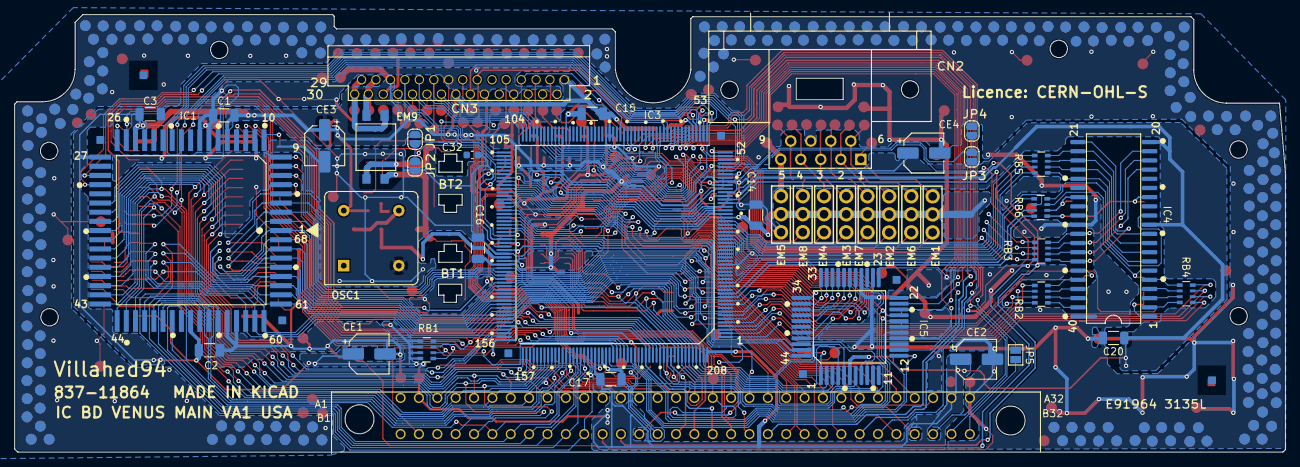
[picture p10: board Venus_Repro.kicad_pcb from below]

Board: 2 copper layers, 175.8 x 60.5 mm, 100 parts (40 on the bottom side), 209 nets.

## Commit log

2026-03-25 Updated Schematic thanks to insight from Oleg Endo
    [Venus_Repro.kicad_sch]
2026-03-25 Added Gerbers in a zip file

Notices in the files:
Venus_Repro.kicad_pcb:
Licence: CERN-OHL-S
